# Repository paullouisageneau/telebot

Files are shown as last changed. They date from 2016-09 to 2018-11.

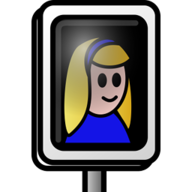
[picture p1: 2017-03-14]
telebot-server/client/android-chrome-192x192.png

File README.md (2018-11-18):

# Telebot
Source code for my telepresence robot

For more information, check my blog articles:

https://chapelierfou.org/2016/09/a-telepresence-robot-building/

https://chapelierfou.org/2016/09/a-telepresence-robot-programming/

https://chapelierfou.org/2017/03/a-telepresence-robot-enhancements/

Telebot

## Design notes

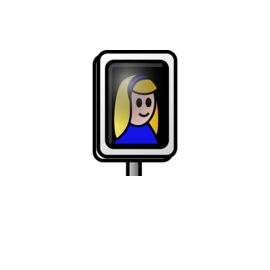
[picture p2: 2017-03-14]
telebot-server/client/mstile-150x150.png

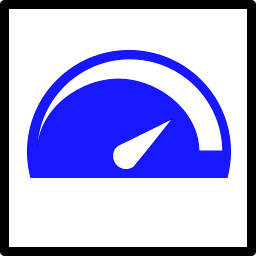
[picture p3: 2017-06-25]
telebot-server/client/button_speed.png

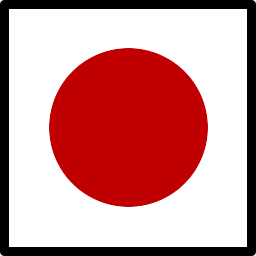
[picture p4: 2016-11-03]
telebot-server/client/button_record.png

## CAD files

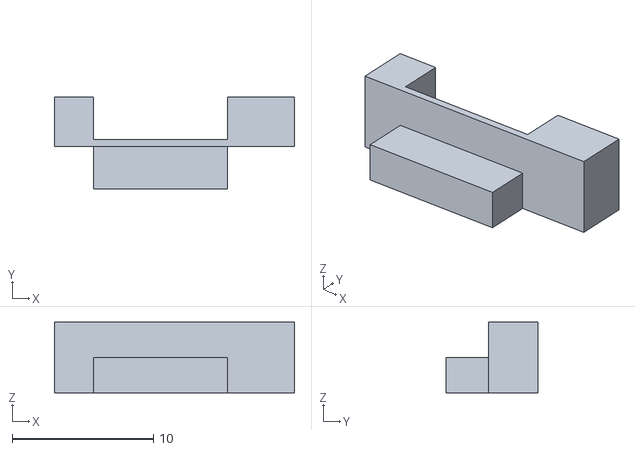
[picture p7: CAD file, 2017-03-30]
models/pad.stl
17.0 x 6.50 x 5.00

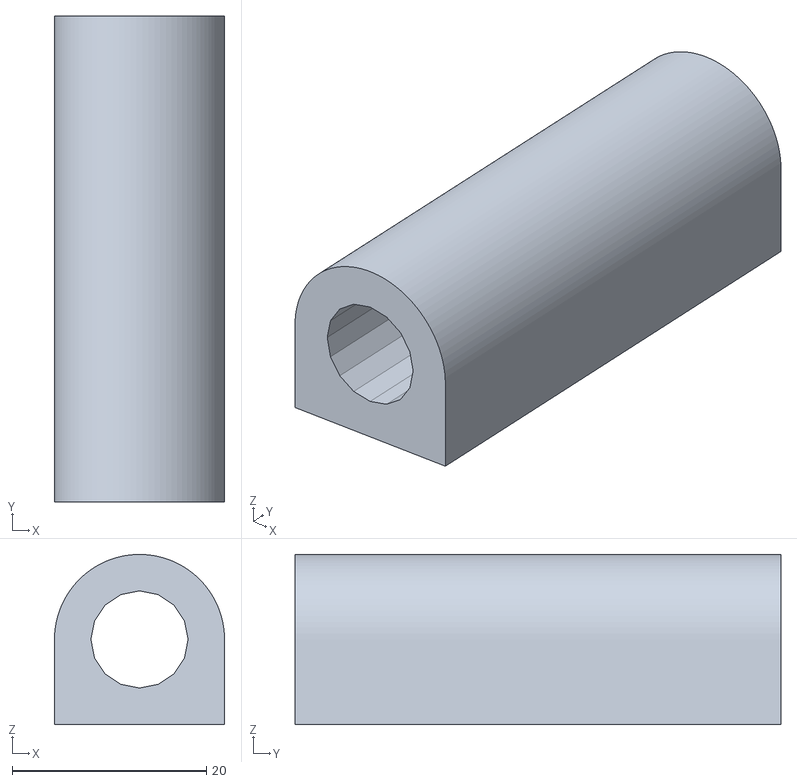
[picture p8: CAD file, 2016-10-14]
models/coupling.stl
17.5 x 50.0 x 17.5

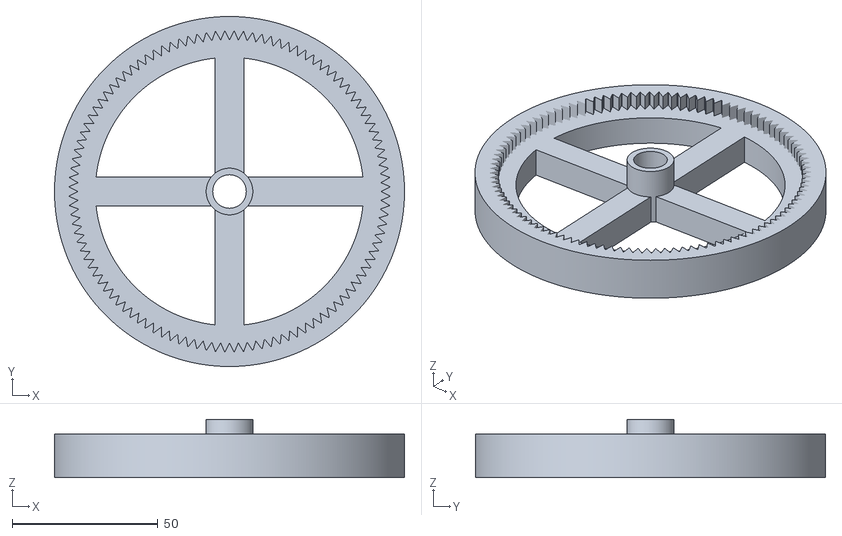
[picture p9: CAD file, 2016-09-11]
models/wheel.stl
120.0 x 120.0 x 20.0

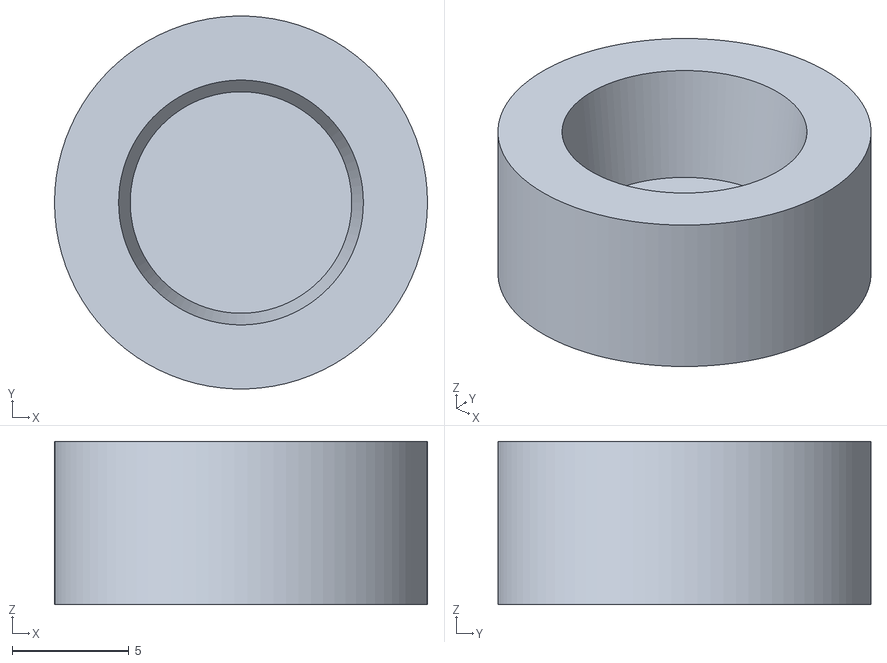
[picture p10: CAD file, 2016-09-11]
models/cap.stl
16.0 x 16.0 x 7.00

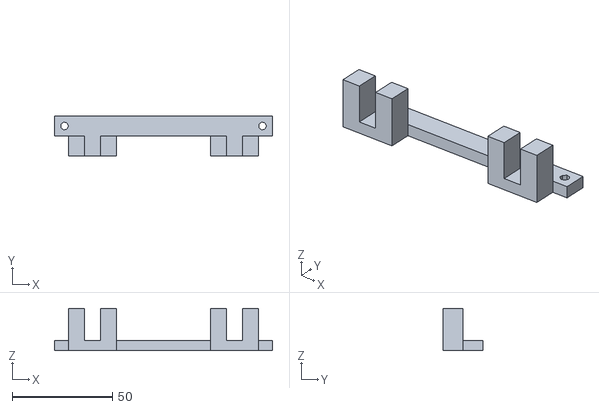
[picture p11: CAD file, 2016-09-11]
models/support2.stl
109.0 x 20.0 x 21.0

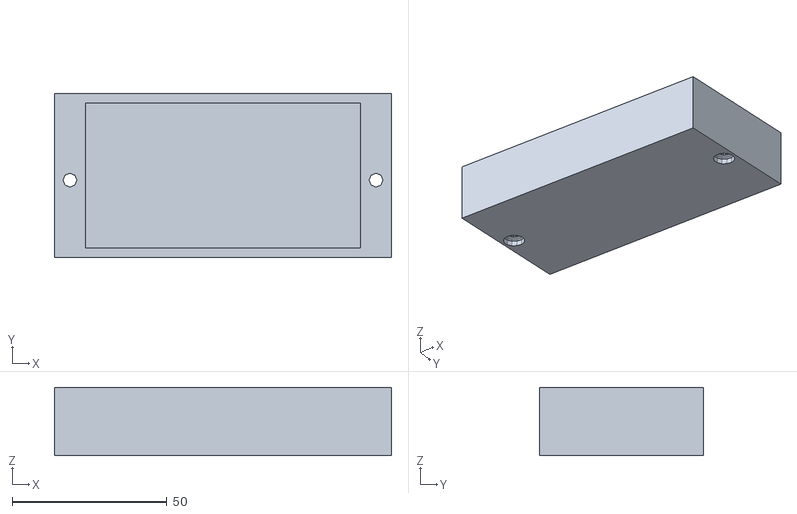
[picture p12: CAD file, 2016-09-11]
models/battery.stl
109.0 x 53.0 x 22.0

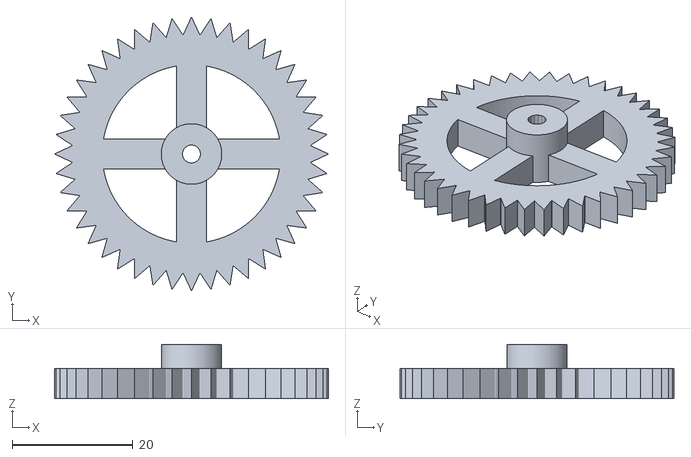
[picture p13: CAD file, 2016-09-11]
models/gear.stl
45.3 x 45.3 x 9.00

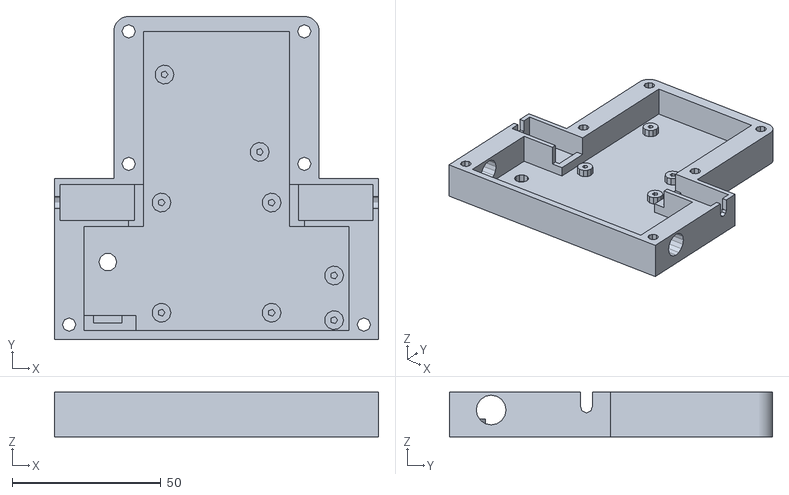
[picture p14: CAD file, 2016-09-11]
models/back.stl
109.0 x 108.5 x 15.0

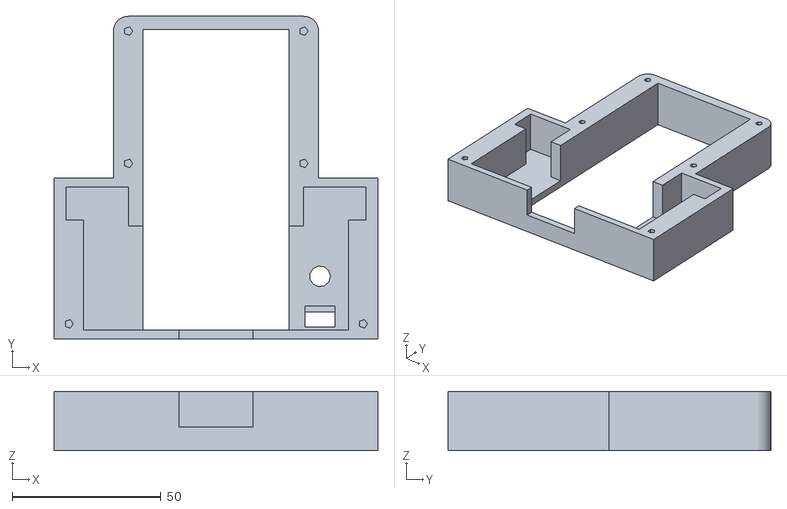
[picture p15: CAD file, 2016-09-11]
models/front.stl
109.0 x 108.5 x 20.0

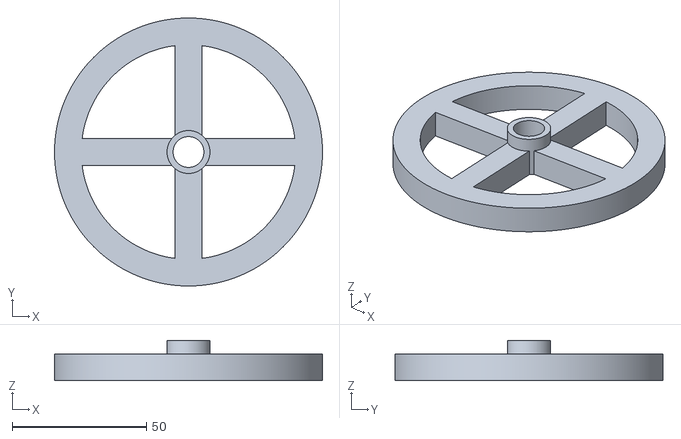
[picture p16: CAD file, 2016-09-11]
models/backwheel.stl
100.0 x 100.0 x 15.0

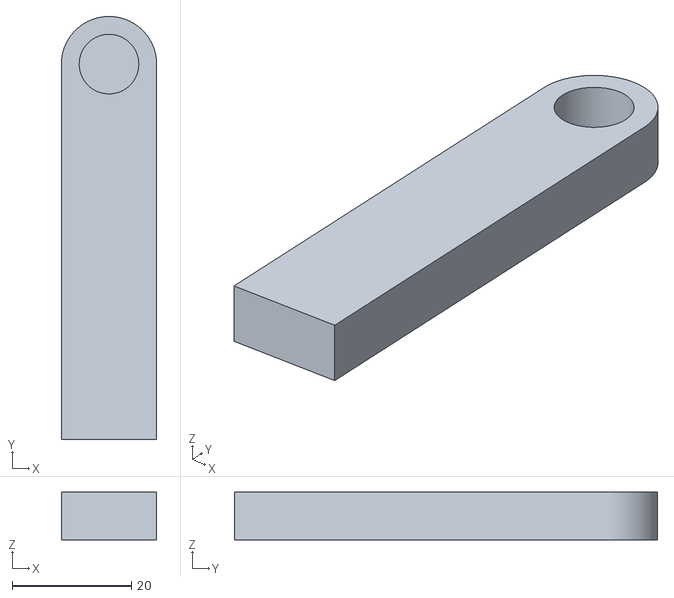
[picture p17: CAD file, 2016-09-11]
models/support.stl
16.0 x 71.0 x 8.00

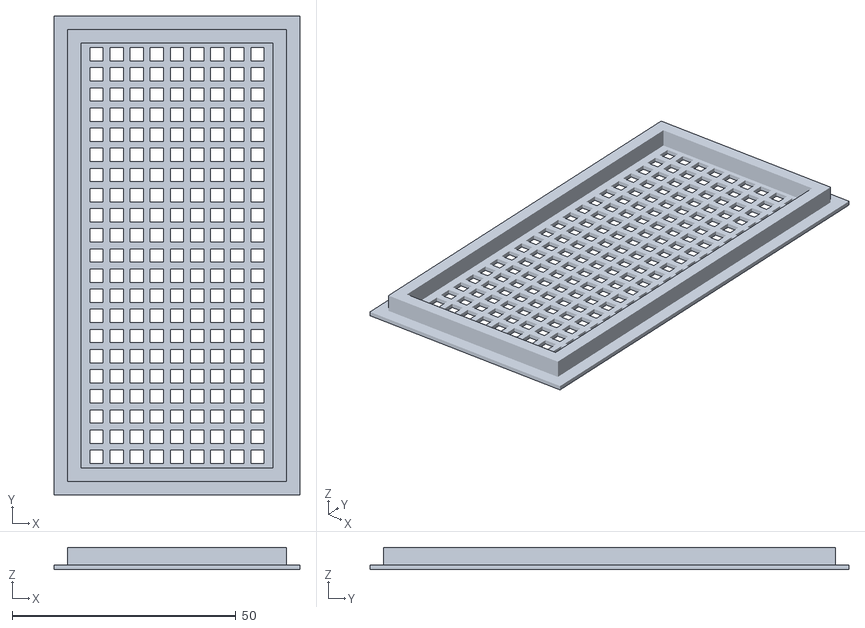
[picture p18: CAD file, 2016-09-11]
models/lid.stl
55.0 x 107.0 x 5.00

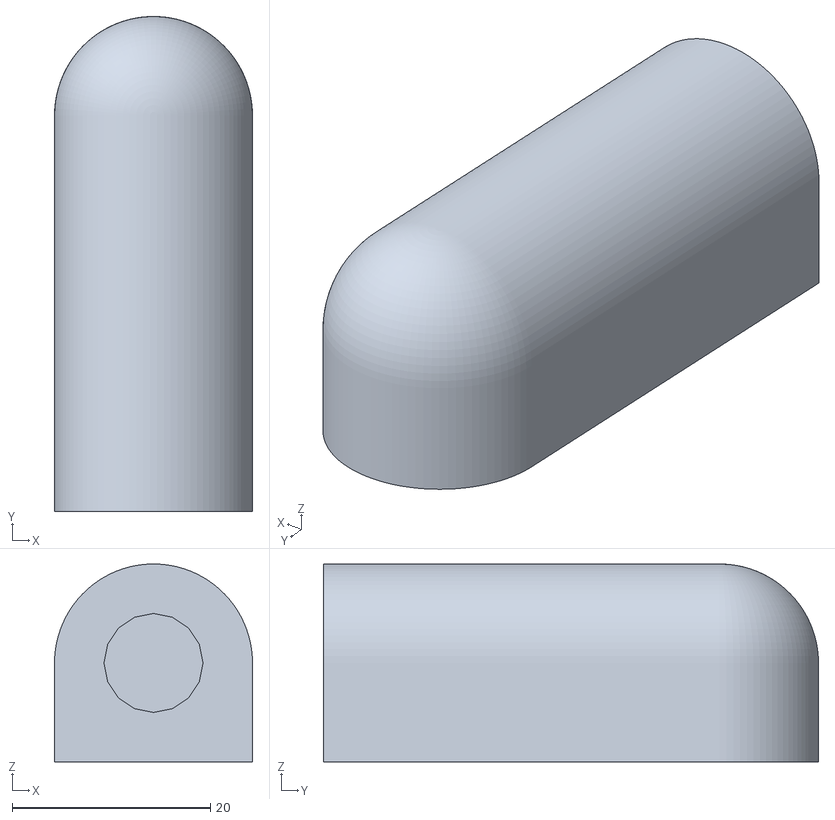
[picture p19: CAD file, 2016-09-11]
models/connector.stl
20.0 x 50.0 x 20.0

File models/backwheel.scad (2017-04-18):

/* 
 * Telebot 1.1
 * Copyright (c) 2015-2016 by Paul-Louis Ageneau
 *
 * This program is free software: you can redistribute it and/or modify
 * it under the terms of the GNU General Public License as published by
 * the Free Software Foundation, either version 3 of the License, or
 * (at your option) any later version.
 *
 * This program is distributed in the hope that it will be useful,
 * but WITHOUT ANY WARRANTY; without even the implied warranty of
 * MERCHANTABILITY or FITNESS FOR A PARTICULAR PURPOSE.  See the
 * GNU General Public License for more details.
 *
 * You should have received a copy of the GNU General Public License
 * along with this program.  If not, see <http://www.gnu.org/licenses/>.
 */

// Back wheel

axis_radius = 5;
radius = 55-10;
thickness = 10;
gap = 5;

union() {
    difference() {
        cylinder(h=thickness, r=radius+5, center=true, $fn=360);
        cylinder(h=thickness+10, r=radius-5, center=true, $fn=360);
    }
    
    difference() {
        union() {
            cube([radius*2,10,thickness], center=true);
            cube([10,radius*2,thickness], center=true);
            translate([0,0,gap/2]) cylinder(h=thickness+gap, r=axis_radius+3, center=true, $fn=90);
        }
        cylinder(h=thickness+gap+gap/2+10, r=axis_radius+0.75, center=true, $fn=90);
    }
}

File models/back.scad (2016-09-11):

/* 
 * Telebot 1.1
 * Copyright (c) 2015-2016 by Paul-Louis Ageneau
 *
 * This program is free software: you can redistribute it and/or modify
 * it under the terms of the GNU General Public License as published by
 * the Free Software Foundation, either version 3 of the License, or
 * (at your option) any later version.
 *
 * This program is distributed in the hope that it will be useful,
 * but WITHOUT ANY WARRANTY; without even the implied warranty of
 * MERCHANTABILITY or FITNESS FOR A PARTICULAR PURPOSE.  See the
 * GNU General Public License for more details.
 *
 * You should have received a copy of the GNU General Public License
 * along with this program.  If not, see <http://www.gnu.org/licenses/>.
 */
 
// Back frame

card_width = 43;
card_height = 48;
card_space = 7;

charger_width = 19;
charger_height = 25;

motor_width = 12;
motor_height = 10;
motor_depth = 25;

wheel_radius = 55;
gear_radius = 5;
axis_offset = -42;
axis_radius = 5;
motor_offset = axis_offset + 55-(20+3);

width = (motor_depth+ 3 + 2 )*2 + card_width + 3*2;
depth = card_height + card_space + card_width + 3*2;
height = motor_height + 3 + 2;
side_thickness = 10;

difference() {
    union() {
        
        difference() {
            translate([0, card_height - depth/2 + 3, -1.5]) cube([width, depth, 3], center = true);	
            union() {
                translate([width/2, card_height+3, 0]) cube([width-card_width-3*2, (card_height - motor_offset - motor_width/2 + 3 - 2)*2, height*2], center = true);
                translate([-width/2, card_height+3, 0]) cube([width-card_width-3*2, (card_height - motor_offset - motor_width/2 + 3 - 2)*2, height*2], center = true);
            }
        }
        
        translate([-width/2 + motor_depth/2 + 5, motor_offset, motor_height/2]) difference() {
            translate([-2.5, 0, 1]) cube([motor_depth+2+3, motor_width+4, motor_height+2], center = true);
            union() {
                translate([-3, 0, 1+2]) cube([motor_depth, motor_width, motor_height+2], center = true);
                translate([motor_depth/2, 0, motor_height/2+2+2]) cube([10, 100, motor_height*2], center = true);
                translate([-motor_depth/2-6, 0, 2]) rotate([0, 90, 0]) cylinder(h=10, r=2, center=true);
                translate([-motor_depth/2-6, 0, motor_height/2+2]) cube([10, 4, motor_height], center = true);
            }
        }
        
        translate([width/2 - motor_depth/2 - 5, motor_offset, motor_height/2]) difference() {
            translate([2.5, 0, 1]) cube([motor_depth+2+3, motor_width+4, motor_height+2], center = true);
            union() {
                translate([3, 0, 1+2]) cube([motor_depth, motor_width, motor_height+2], center = true);
                translate([-motor_depth/2, 0, motor_height/2+2+2]) cube([10, 100, motor_height*2], center = true);
                translate([motor_depth/2+6, 0, 2]) rotate([0, 90, 0]) cylinder(h=10, r=2, center=true);
                translate([motor_depth/2+6, 0, motor_height/2+2]) cube([10, 4, motor_height], center = true);
            }
        }
        
        translate([0, card_height + side_thickness/2-3, height/2 - 3]) cube([card_width+3*2+side_thickness, side_thickness/2, height], center = true);
        translate([0, -depth+card_height+3/2, height/2 - 3]) cube([width, 3, height], center = true);

        translate([(width-card_width-side_thickness + 3)/2, card_height - side_thickness/2 + 3/2 + 3, height/2 - 3]) cylinder(h=height, r=side_thickness/2, center = true, $fn=90);
        translate([-(width-card_width-side_thickness + 3)/2, card_height - side_thickness/2 + 3/2 + 3, height/2 - 3]) cylinder(h=height, r=side_thickness/2, center = true, $fn=90);

        translate([(width-card_width-side_thickness + 3)/2, card_height - (card_height - motor_offset - motor_width/2)/2, height/2 - 3]) cube([side_thickness, card_height - motor_offset - motor_width/2, height], center = true);
        translate([-(width-card_width-side_thickness + 3)/2, card_height - (card_height - motor_offset - motor_width/2)/2, height/2 - 3]) cube([side_thickness, card_height - motor_offset - motor_width/2, height], center = true);

        difference() {
            union() {
                translate([-width/2+side_thickness/2, (motor_offset - motor_width/2 -depth+card_height+3)/2, height/2 - 3]) cube([side_thickness, motor_offset - motor_width/2 + depth-card_height - 3, height], center = true);
                translate([width/2-side_thickness/2, (motor_offset - motor_width/2 -depth+card_height+3)/2, height/2 - 3]) cube([side_thickness, motor_offset - motor_width/2 + depth-card_height - 3, height], center = true);
            }
            translate([0, axis_offset, motor_height/2 + 2 - 1]) rotate([0, 90, 0]) cylinder(h=200, r=axis_radius, center=true);
        }
        
        // L298N
        translate([-37/2, -card_space-40, 0]) screw(3);
        translate([37/2,  -card_space-40, 0]) screw(3);
        translate([-37/2, -card_space-3, 0]) screw(3);
        translate([37/2,  -card_space-3, 0]) screw(3);
        
        // MPU6050
        translate([width/2-side_thickness-5,  axis_offset+7.5, 0]) screw(3);
        translate([width/2-side_thickness-5,  axis_offset-7.5, 0]) screw(3);
        
        // Chevino 2.0
        translate([card_width/2-7,  7, 0]) screw(3);
        translate([-card_width/2+4, 33,  0]) screw(3);
        
        // Charger
        translate([-card_width/2-15-charger_width/2, -card_space-card_height+2, 0]) cube([charger_width, 5, height+13-charger_height], center = false);
        translate([-card_width/2-15, -card_space-card_height+5.75, height+13-charger_height+1.5]) cube([charger_width/2, 2.5, 3], center = true);
    }
    
    union() {
        translate([width/2-side_thickness/2, -card_height-card_space+side_thickness/2-1, 0]) 
            screw_hole(3);
        translate([-width/2+side_thickness/2, -card_height-card_space+side_thickness/2-1, 0]) 
            screw_hole(3);
        translate([(width-card_width-side_thickness + 3)/2, card_height-0.5, 0]) 
            screw_hole(3);
        translate([-(width-card_width-side_thickness + 3)/2, card_height-0.5, 0]) 
            screw_hole(3);
        translate([(width-card_width-side_thickness + 3)/2, 3, 0]) 
            screw_hole(3);
        translate([-(width-card_width-side_thickness + 3)/2, 3, 0]) 
            screw_hole(3);
        
        translate([width/2-side_thickness/2, -depth+card_height+26, 0])
            screw_hole_battery(12);
        translate([-width/2+side_thickness/2, -depth+card_height+26, 0])
            screw_hole_battery(12);
        
        translate([-card_width/2-15, -30, 0]) cylinder(h = 100, r = 3, center=true);
    }
}

module screw(height = 3)
{
    translate([0, 0, height/2]) difference() {
            cylinder(h = height, r=3.20, center=true);
            cylinder(h = height+1, r=1.20, center=true);
    }
}

module screw_hole(depth = 3)
{
    union() {
            cylinder(h = height*2, r = 2.25, center=true);
            translate([0, 0, -3]) cylinder(h = depth*2, r = 4, center=true);
            translate([0, 0, depth-3]) scale([1,1,0.25]) sphere(r = 4, center = true);
    }
}

module screw_hole_battery(depth = 15)
{
    translate([0, 0, -3]) cylinder(h = depth*2, r = 1.5, center=true);
}

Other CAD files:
models/wheel.scad
models/battery.scad
models/cap.scad
models/connector.scad
models/coupling.scad
models/front.scad
models/gear.scad
models/lid.scad
models/pad.scad
models/support.scad
models/support2.scad

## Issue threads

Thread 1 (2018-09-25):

at launching of app it throws java.io.IOException: Unable to connect Bluetooth device

bha2020, 2018-09-25:
org.ageneau.telebot W/System.err: java.io.IOException: Unable to connect Bluetooth device
09-25 11:57:45.396 12382-12403/org.ageneau.telebot W/System.err:     at org.ageneau.telebot.SerialHandler.connect(SerialHandler.java:106)
        at org.ageneau.telebot.SerialHandler.<init>(SerialHandler.java:65)
        at org.ageneau.telebot.TelebotActivity$1.run(TelebotActivity.java:154)
        at android.os.AsyncTask$SerialExecutor$1.run(AsyncTask.java:234)
        at java.util.concurrent.ThreadPoolExecutor.runWorker(ThreadPoolExecutor.java:1113)
        at java.util.concurrent.ThreadPoolExecutor$Worker.run(ThreadPoolExecutor.java:588)
        at java.lang.Thread.run(Thread.java:818)

please help

paullouisageneau, 2018-09-25:
The exception means the Bluetooth device of the Telebot was not found. Check that:
- it is named "telebot" (like explained in the blog article)
- it is paired with the phone/tablet
- it is turned on

bha2020, 2018-09-26:
Thank you for your reply.
Done all the settings as you mentioned but still getting same exception.

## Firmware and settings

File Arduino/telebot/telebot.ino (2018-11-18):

/*
 * Telebot Arduino program
 * Copyright (c) 2015-2017 by Paul-Louis Ageneau
 *
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
 * You should have received a copy of the GNU General Public License
 * along with this program.  If not, see <http://www.gnu.org/licenses/>.
 */

#define USE_SOFTI2C // Use SoftI2C rather than Wire
#define MPU 0x68    // I2C address of the MPU-6050

#include <SoftwareSerial.h>
#ifdef USE_SOFTI2C
#define SDA_PORT PORTC
#define SDA_PIN 4       // A4
#define SCL_PORT PORTC
#define SCL_PIN 5       // A5
#define I2C_SLOWMODE 1  // Limit to 25kHz
#define I2C_TIMEOUT 10  // 10ms timeout
#define ADDR(x) (x << 1)
#include <SoftI2CMaster.h>
#else
#include <Wire.h>
#endif

// ---------- Pin setup ----------
const int motorLeftBackwardPin  = 2;
const int motorLeftForwardPin   = 3;
const int motorLeftEnablePin    = 5;
const int motorRightBackwardPin = 7;
const int motorRightForwardPin  = 4;
const int motorRightEnablePin   = 6;
const int batteryProbePin       = A0;

SoftwareSerial bluetooth(8, 9); // TX, RX

const long batteryProbeFactor = 4888L;  // Adjust for another board
//const long batteryProbeFactor = 4106L;

// ----------- Timings -----------
const long stepMillis = 10L;
const long calibrationMillis = 2000L;

// ----------- Motors ------------
const long k1 = 2000L;	// Adjust k1 and k2 depending on motors
const long k2 = 400L;

long controlFactor = 1000L; // Adjust factor depending on motors

const int motorMin = 64;
const int motorMax = 255;

const int powerMin = 100;

// -------------------------------

unsigned long oldmicros = 0L;
String inputString = "";

long steps = 0L;
long rotx0 = 0L;
long rotxl = 0L;
long accz0 = 0L;
long acczl = 0L;
long angx  = 0L;

// Current motor controls
int motorRightPower   = 0;
int motorLeftPower    = 0;
int commandRightPower = 0;
int commandLeftPower  = 0;
int tempRightPower    = 0;
int tempLeftPower     = 0;

int batteryProbeCount = 0;

// Set right motor power in [-1000, 1000]
void motorRight(int power)
{
  if(abs(power) < powerMin) power = 0;
  power = constrain(power, -1000, 1000);
  digitalWrite(motorRightBackwardPin, (power < 0 ? HIGH : LOW));
  digitalWrite(motorRightForwardPin,  (power > 0 ? HIGH : LOW));
  if(power != 0) analogWrite(motorRightEnablePin, map(abs(power), 0, 1000, motorMin, motorMax));
  else analogWrite(motorRightEnablePin, 0);
}

// Set left motor power in [-1000, 1000]
void motorLeft(int power)
{
  if(abs(power) < powerMin) power = 0;
  power = constrain(power, -1000, 1000);
  digitalWrite(motorLeftBackwardPin, (power < 0 ? HIGH : LOW));
  digitalWrite(motorLeftForwardPin,  (power > 0 ? HIGH : LOW));
  if(power != 0) analogWrite(motorLeftEnablePin, map(abs(power), 0, 1000, motorMin, motorMax));
  else analogWrite(motorLeftEnablePin, 0);
}

// Init I2C connection
void initWire(void)
{
#ifdef USE_SOFTI2C
  i2c_init();
  i2c_start_wait(ADDR(MPU) | I2C_WRITE);
  i2c_write(0x6B);  // PWR_MGMT_1 register
  i2c_write(0x00);  // set to zero (wakes up the MPU-6050)
  i2c_stop();
#else
  Wire.begin();
  TWBR = ((F_CPU / 100000L) - 16) / 2; // Set I2C frequency to 100kHz
  Wire.beginTransmission(MPU);
  Wire.write(0x6B); // PWR_MGMT_1 register
  Wire.write(0X00); // set to zero (wakes up the MPU-6050)
  Wire.endTransmission(true);
#endif
}

void setup(void) 
{
  // Init pins
  pinMode(motorRightBackwardPin, OUTPUT);
  pinMode(motorRightForwardPin, OUTPUT);
  pinMode(motorRightEnablePin, OUTPUT);
  pinMode(motorLeftBackwardPin, OUTPUT);
  pinMode(motorLeftForwardPin, OUTPUT);
  pinMode(motorLeftEnablePin, OUTPUT);

  // Init serials
  Serial.begin(9600);
  bluetooth.begin(9600);  // HC-06 defaults to 9600bps
  inputString.reserve(100);

  // Init I2C
  initWire();
}

void loop(void) 
{
  oldmicros = micros();
  
  int batteryVoltage = int(long(analogRead(batteryProbePin))*batteryProbeFactor/1000L);  // mV
  int batteryPercent = constrain(map(batteryVoltage, 3200, 4200, 0, 100), 0, 100);

  // Read commands on bluetooth serial
  while(bluetooth.available())
  {
    char chr = (char)bluetooth.read();
    if(chr != '\n') 
    {
      if(chr != '\r')
        inputString+= chr;
    }
    else if(inputString.length() > 0)
    {
        char cmd = inputString[0];
        String param;
        int pos = 1;
        while(pos < inputString.length() && inputString[pos] == ' ') ++pos;
        param = inputString.substring(pos);

        int value = 0;
        switch(cmd)
        {
        case 'L': // left
          value = constrain(param.toInt(), -100, 100)*10;
          tempLeftPower = int(long(value)*controlFactor/1000L);
          break;
        case 'R': // right
          value = constrain(param.toInt(), -100, 100)*10;
          tempRightPower = int(long(value)*controlFactor/1000L);
          break;
        case 'C': // commit
          commandLeftPower  = tempLeftPower;
          commandRightPower = tempRightPower;
          break;
        case 'B': // battery
          bluetooth.print("B ");
          bluetooth.print(batteryPercent);
          bluetooth.println();
          break;
        default:
          bluetooth.println("E");
          break; 
        }
        inputString = "";
    }
  }

  // Stop motors and exit program on low battery
  if(batteryPercent == 0)
  {
    ++batteryProbeCount;
    if(batteryProbeCount == 10)
    {
      bluetooth.print("B 0");
      bluetooth.println();
      motorRight(0);
      motorLeft(0);
      exit(0);
    }
  }
  else {
    batteryProbeCount = 0;
  }

#ifdef USE_SOFTI2C
  if(i2c_start(ADDR(MPU) | I2C_WRITE))
  {
    i2c_write(0x3B);  // starting with register 0x3B (ACCEL_XOUT_H)
    i2c_rep_start(ADDR(MPU) | I2C_READ);

    long accx = i2c_read(false)<<8 | i2c_read(false);  // 0x3B (ACCEL_XOUT_H) & 0x3C (ACCEL_XOUT_L)    
    long accy = i2c_read(false)<<8 | i2c_read(false);  // 0x3D (ACCEL_YOUT_H) & 0x3E (ACCEL_YOUT_L)
    long accz = i2c_read(false)<<8 | i2c_read(false);  // 0x3F (ACCEL_ZOUT_H) & 0x40 (ACCEL_ZOUT_L)
    long temp = i2c_read(false)<<8 | i2c_read(false);  // 0x41 (TEMP_OUT_H) & 0x42 (TEMP_OUT_L)
    long rotx = i2c_read(false)<<8 | i2c_read(false);  // 0x43 (GYRO_XOUT_H) & 0x44 (GYRO_XOUT_L)
    long roty = i2c_read(false)<<8 | i2c_read(false);  // 0x45 (GYRO_YOUT_H) & 0x46 (GYRO_YOUT_L)
    long rotz = i2c_read(false)<<8 | i2c_read(true);   // 0x47 (GYRO_ZOUT_H) & 0x48 (GYRO_ZOUT_L)

    i2c_stop();
#else
  Wire.beginTransmission(MPU);
  Wire.write(0x3B);                     // starting with register 0x3B (ACCEL_XOUT_H)
  if(Wire.endTransmission(false) == 0)
  {
    Wire.requestFrom(MPU, 14, true);    // request 14 registers and release

    long accx = Wire.read()<<8|Wire.read();  // 0x3B (ACCEL_XOUT_H) & 0x3C (ACCEL_XOUT_L)    
    long accy = Wire.read()<<8|Wire.read();  // 0x3D (ACCEL_YOUT_H) & 0x3E (ACCEL_YOUT_L)
    long accz = Wire.read()<<8|Wire.read();  // 0x3F (ACCEL_ZOUT_H) & 0x40 (ACCEL_ZOUT_L)
    long temp = Wire.read()<<8|Wire.read();  // 0x41 (TEMP_OUT_H) & 0x42 (TEMP_OUT_L)
    long rotx = Wire.read()<<8|Wire.read();  // 0x43 (GYRO_XOUT_H) & 0x44 (GYRO_XOUT_L)
    long roty = Wire.read()<<8|Wire.read();  // 0x45 (GYRO_YOUT_H) & 0x46 (GYRO_YOUT_L)
    long rotz = Wire.read()<<8|Wire.read();  // 0x47 (GYRO_ZOUT_H) & 0x48 (GYRO_ZOUT_L)
#endif
      
    // Note: temperature in Celsius is temp/340.00+36.53

    rotx*= 1000;	  // all values are in millis
    accz*= 1000;

    // Calibration
    if(millis() <= calibrationMillis)
    {
      // Estimate idle input values
      rotx0 = (rotx0*steps + rotx)/(steps+1);
      accz0 = (accz0*steps + accz)/(steps+1);
      
      /*Serial.print("rotx0=");
      Serial.print(rotx0);
      Serial.print(",\taccz0=");
      Serial.print(accz0);
      Serial.println();*/
    }
    else {
      // Update idle input values
      const long gamma1 = 1000L;
      const long gamma2 = 1000L;
      rotx0 = (rotx0*(gamma1-1) + rotx)/gamma1;
      accz0 = (accz0*(gamma2-1) + accz)/gamma2;
      
      // Center inputs
      rotx = rotx - rotx0;
      accz = accz - accz0;

      // Smooth
      const long alpha = 10L;
      rotxl = (rotxl*(alpha-1) + rotx)/alpha;
      acczl = (acczl*(alpha-1) + accz)/alpha;
      
      // Integrate rotation
      angx+= rotx*stepMillis/1000L;

      // Recalibrate angle according to gravity
      const long g = 10L;
      const long beta = 100L;
      angx = (angx*(beta-1) - acczl/g)/beta;
      
      /*Serial.print("rotx=");
      Serial.print(rotx);
      Serial.print(",\taccz=");
      Serial.print(accz);
      Serial.print(",\tangx=");
      Serial.print(angx);
      Serial.println();*/

      // Linear correction with rotation and angle
      long correction = rotxl/k1 + angx/k2;
      correction = constrain(correction, -2000, 2000);
  
      /*Serial.print("correction=");
      Serial.println(correction);*/
      
      // Adjust motors
      long motorRightPower = constrain(commandRightPower + int(correction), -1000, 1000);
      long motorLeftPower  = constrain(commandLeftPower  + int(correction), -1000, 1000);
      motorRight(motorRightPower);
      motorLeft(motorLeftPower);
    }
  }
  else {
    // Something is wrong with I2C, try to reinit
    motorRight(0);
    motorLeft(0);
    initWire();
  }
  
  long elapsed = (micros() - oldmicros);
  long t = max(0L, stepMillis*1000L - elapsed);
  if(t) delayMicroseconds(t);

  ++steps;
}

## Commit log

2016-09-04 Call button disabled until status is online
2016-09-11 Added models with SCAD and STL files
    [back.scad, back.stl, backwheel.scad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]
2016-09-16 Adjusted power and balancing
2016-09-29 Fixed server control flow and logging
2016-10-14 Added coupling model
    [coupling.scad, coupling.stl]
2016-10-14 Added missing echo
    [gear.scad]
2016-10-29 Added battery probe count
2016-10-31 Fixed redefinition of k1 and k2
    [telebot.ino]
2016-11-03 Enhanced motor control in Arduino code
2016-11-03 Added record button to interface
2016-11-03 Fixed parenthesis in voltage calculation
    [telebot.ino]
2017-02-03 Fixed gamma for idle
    [telebot.ino]
2017-03-30 Control now uses WebRTC data channel and local server
    [pad.scad, pad.stl]
2017-04-01 Added some comments in Arduino code
2017-04-18 Renamed height to thickness
    [backwheel.scad, gear.scad]
2017-05-07 Added support for Bluetooth auto-reconnection and battery status display
2017-05-10 Higher k1 to prevent vibrations
    [telebot.ino]
2017-06-25 Added speed button
2017-06-25 Some fixes for button handling
2017-06-25 Better button speed color
2017-07-11 Fixed battery probe constant
    [telebot.ino]
2017-10-03 Added powerMin
2019-07-07 Fixed case with object-fit
